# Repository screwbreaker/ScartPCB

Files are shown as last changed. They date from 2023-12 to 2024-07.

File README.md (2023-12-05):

# ScartPCB
A little PCB to buld a SCART cable for console and old computers

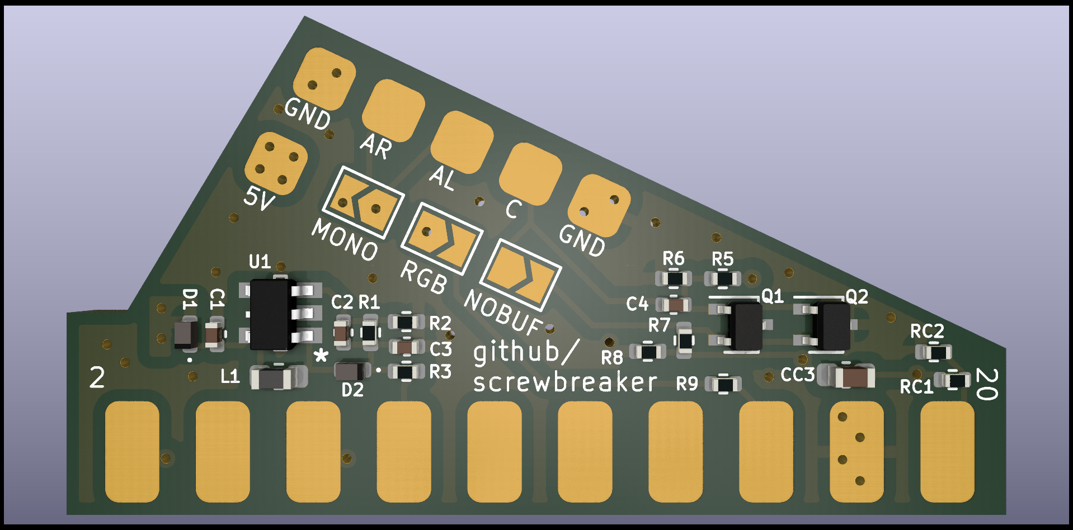
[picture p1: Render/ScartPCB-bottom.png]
Board


### Summary
This is a little PCB made to make easy to assemble a SCART cable for console and old computers.

### History
As anyone else I always made my SCART cables by hand, using THT components. And by soldering them directly on the SCART connector.
And that's pefectly fine. Except for systems like the Mega Drive, that require a lot of componets to be fitted in a small space.
So I thought to build a little PCB that fit inside the SCART connector in oder to make everything more easy and clean.

As example here a comparison between my old handmade cable, and the new one with this PCB:
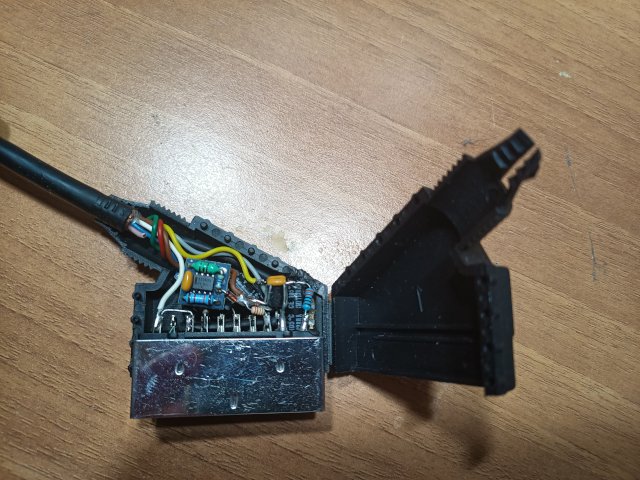
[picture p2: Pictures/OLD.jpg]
OLD

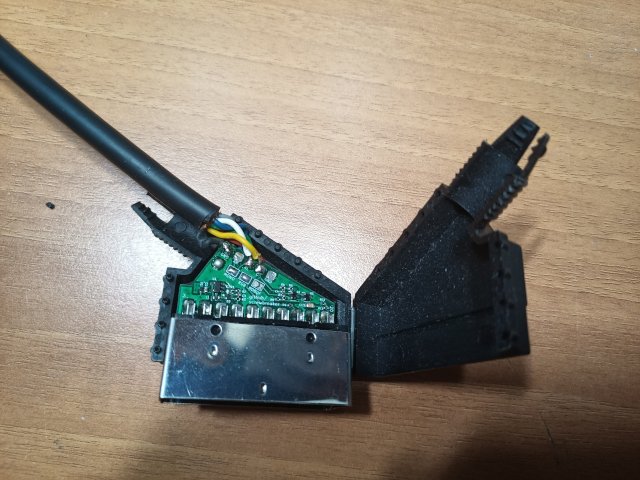
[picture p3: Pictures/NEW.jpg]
NEW


Of course, there are other project like this around. But none of them have all the stuff I wanted.
My requirements was a buffer for the csync and a boost converter for the 12V.

My original plan was to make a PCB for each console.
But, I managed this PCB in a way that can be used almost in any case.
With this PCB is possible to make a SCART cable for almost every console and computer. It is pretty versatile.
And is made to fit inside the cheapest SCART connectors available online.

### Basic informations
The components value in the schematic and in the BOM are for a PAL Mega Drive.
For other systems, refer to the SCART diagram of the secific system.

### How it work
The PCB allow to put components in series and in parallel with the signals.
This allow to use this PCB to buld almost any SCART cable for almost any system.

To make a Mega Drive cable is necessary to put a 220uF capacitor in series with the RGB signals, since is really complicated to find small, and cheap SMD capacitors of this value, the PCB allow to put multiple capacitors in parallel. So, to make a 220uF capacitor is possible to put two 100uF 1206 plus one 22uF 0603.
Probably the 22uF are not really required, but I found the space for some extra footprint in the PCB, so the total value can be easily adjusted.

For example to make a SNES cable put a 0 ohm resistor in place of RR1, RG1, RB1, and place a 75 ohm resitor to ground on each singal by using RR2, RG2, RB2.

If you have a mono audio, like in the first model of Mega Drive, is possible to close the MONO jumper, this short toghether the left and right channel.

The video buffer is there mostly for the Mega Drive, it is nor required on most of the other systems.
To bypass the video buffer, close the NOBUF jumper, in this case do not populate any components on the buffer section.

The RGB jumper can be left open on systems that don't have an RGB output, like a C64.

In general, choose the components to match what do you need to make your video cable. By using 0 ohm resistors as jumper is possible to make almost any combination.

### Csync buffer
The Mega Drive have a problem with the csync signal.
The csync is connected to the input pin of the encoder, not to the output pin.
This can cause some issue on some TV sets. That's why I placed a buffer on the line.

The csync on the Mega Drive is also a TTL level signal, to compensate this a 300-470 ohm reistor can be placed in series with the signal to reduce the voltage to something more like to the standard.
Most of the time also a 220uF capacitor in series with the signal is required.
Not only the Mega Drive use a TTL signal on the csync, it cab be present also on other systems.

Unfortunately not all TV do like this values for the csync line.
So, the values can be adjusted to match your TV set requirements.
Be careful with the level of the signals, they must be in a range that do not cause any damage to your TV.

The values on the csync line, that are on the schematic or in the BOM are for a PAL Mega Drive.
With this set of components I can use my modded MD on my TV, by switching from PAL to NTSC withouth any issue.

Other systems don't have this issue.
The buffer can be bypassed if not needed by closing the NOBUF jumper.
In this case, do not populate any component on the buffer section.

### 12V booster
There is a little boost converter to step up the 5V and get the 12V required for the 4:3 aspect ration.
This is the only way to have the switch voltage.
Some systems, like Amiga or SNES do have the 12V on the connector. But, due to the small space on the PCB, is not possible to use it.

### BOM
The BOM is for a PAL Mega Drive.
To make SCART cables for other system choose the components according to the specific schematic.
Use 0 ohm resistors as jumper where needed.

For the boost converter TPS61040DBVR and TPS61041DBVR are equivalent for this application.

For the buffer any pair of complementary transistors can be used, the package must be SC-70 or equivalent.

### PCB Manufacturing
Unfortunately, due to the space constraints inside the SCART connector, this PCB is a 4 layer board.
And for the same reason, some components are 0402.

The PCB still very cheap to produce, since it is very small, and it use standard vias and traces.

Soldering 0402 components by hand require a bit of skill on soldering.

### Bonus
All the SCART connectors I bought have an hawful issue. The cable gland, the plastic thing that close the SCART shell, is made out the most brittle material in the world.
Initially, I thought that this was because I bought the cheapest SCART connector available on internet.
However even the ones bought on trusth resellers or on electronic shops have this issue.
So, I made a replacement that can be 3D printed. It's far to be perfect, I have no skills on 3D printing. But it do the job.
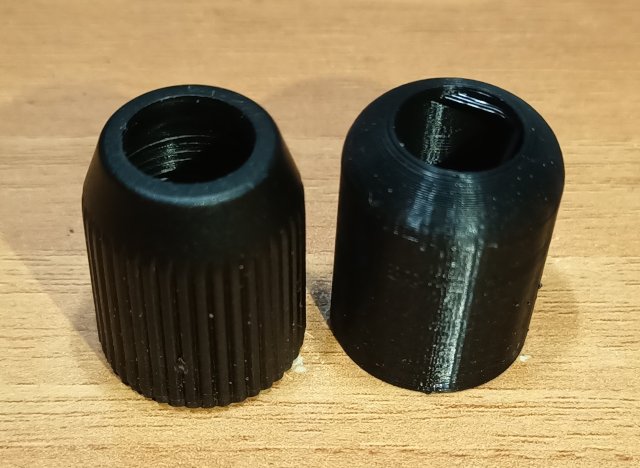
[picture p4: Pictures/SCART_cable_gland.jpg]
SCART_cable_gland


### License
The PCBs are under the CERN OHL license.
The firmwares, under the GPL3.

This is an OPEN project.
So, like any other project like this, the hope is that others can improve it an reshare with the community.
Don't go out this basic guideline.

### Disclaimer
The hardware and the software are provided to you 'as is' and without any express or implied warranties whatsoever with respect to its functionality, operability or use, including, without limitation, any implied warranties of merchantability, fitness for a particular purpose or infringement. We expressly disclaim any liability whatsoever for any direct, indirect, consequential, incidental or special damages, including, without limitation, lost revenues, lost profits, losses resulting from business interruption or loss of data, regardless of the form of action or legal theory under which the liability may be asserted, even if advised of the possibility or likelihood of such damages.

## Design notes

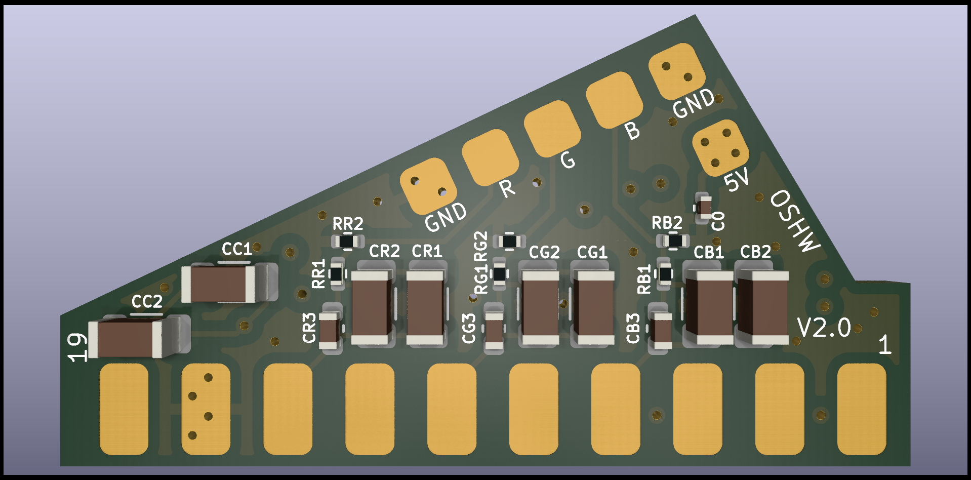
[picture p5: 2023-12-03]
Render/ScartPCB-top.png

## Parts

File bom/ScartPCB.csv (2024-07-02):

Source: | /home/francesco/KiCad_Projects/ScartPCB/ScartPCB.kicad_sch
Date: | mar 2 lug 2024, 21:53:10
Tool: | Eeschema 6.0.11-2627ca5db0~126~ubuntu20.04.1
Generator: | /usr/share/kicad/plugins/bom_csv_grouped_by_value.py
Component Count: | 34
Individual Components:
Item | Qty | Reference(s) | Value | LibPart | Footprint | Datasheet | Datasheet | Description | Footprint | Manufacturer | Manufacturer_Part_Number | Package | Reference | Value
 |  | C0 | 100nF | Device:C | Capacitor_SMD:C_0402_1005Metric | https://www.mouser.it/datasheet/2/447/UPY_NP0X5R_01005_4V_to_25V_V10-3003057.pdf | ~ | 16V 100nF X7R ±10% 0402 Multilayer Ceramic Capacitors MLCC - SMD/SMT ROHS |  | YAEGO | CC0402KRX7R7BB104 | 0402 | C | C
 |  | C1 | 4.7uF | Device:C | Capacitor_SMD:C_0402_1005Metric | https://eu.mouser.com/datasheet/2/40/Kyocera_AVX_Components_CT_Series_e-2933596.pdf | ~ | 0402 Multilayer Ceramic Capacitors MLCC - SMD/SMT ROHS |  | Kyocera AVX | CM05X5R475M25AH | 0402 | C | C
 |  | C2 | 10pF | Device:C | Capacitor_SMD:C_0402_1005Metric | https://www.mouser.it/datasheet/2/210/WTC_MLCC_General_Purpose-1534899.pdf | ~ | 50V 10pF NP0 ±5% 0402 Multilayer Ceramic Capacitors MLCC - SMD/SMT ROHS |  | Walsin | 0402N100J500CT | 0402 | C | C
 |  | C3 | 1uF | Device:C | Capacitor_SMD:C_0402_1005Metric | https://eu.mouser.com/datasheet/2/281/1/GRM155R61E105MA12_01A-1983855.pdf | ~ | 0402 Multilayer Ceramic Capacitors MLCC - SMD/SMT ROHS |  | Murata Electronics | GRM155R61E105MA12D | 0402 | C | C
 |  | C4 | 100nF | Device:C | Capacitor_SMD:C_0402_1005Metric | https://www.mouser.it/datasheet/2/447/UPY_NP0X5R_01005_4V_to_25V_V10-3003057.pdf | ~ | 16V 100nF X7R ±10% 0402 Multilayer Ceramic Capacitors MLCC - SMD/SMT ROHS |  | YAEGO | CC0402KRX7R7BB104 | 0402 | C | C
 |  | CB1 | 100uF | Device:C | Capacitor_SMD:C_1206_3216Metric | https://eu.mouser.com/datasheet/2/281/1/GRM31CR61A107ME05_01A-2066674.pdf | ~ | 10V 100uF X5R ±20% 1206 Multilayer Ceramic Capacitors MLCC - SMD/SMT ROHS |  | Murata Electronics | GRM31CR61A107ME05L | 1206 | C | C
 |  | CB2 | 100uF | Device:C | Capacitor_SMD:C_1206_3216Metric | https://eu.mouser.com/datasheet/2/281/1/GRM31CR61A107ME05_01A-2066674.pdf | ~ | 10V 100uF X5R ±20% 1206 Multilayer Ceramic Capacitors MLCC - SMD/SMT ROHS |  | Murata Electronics | GRM31CR61A107ME05L | 1206 | C | C
 |  | CB3 | 22uF | Device:C | Capacitor_SMD:C_0603_1608Metric | https://eu.mouser.com/datasheet/2/585/MLCC-1837944.pdf | ~ | 10V 22uF X5R ±20% 0603 Multilayer Ceramic Capacitors MLCC - SMD/SMT ROHS |  | Samsung | CL10A226MP8NUNE | 0603 | C | C
 |  | CC1 | 100uF | Device:C | Capacitor_SMD:C_1206_3216Metric | https://eu.mouser.com/datasheet/2/281/1/GRM31CR61A107ME05_01A-2066674.pdf | ~ | 10V 100uF X5R ±20% 1206 Multilayer Ceramic Capacitors MLCC - SMD/SMT ROHS |  | Murata Electronics | GRM31CR61A107ME05L | 1206 | C | C
 |  | CC2 | 100uF | Device:C | Capacitor_SMD:C_1206_3216Metric | https://eu.mouser.com/datasheet/2/281/1/GRM31CR61A107ME05_01A-2066674.pdf | ~ | 10V 100uF X5R ±20% 1206 Multilayer Ceramic Capacitors MLCC - SMD/SMT ROHS |  | Murata Electronics | GRM31CR61A107ME05L | 1206 | C | C
 |  | CC3 | 22uF | Device:C | Capacitor_SMD:C_0603_1608Metric | https://eu.mouser.com/datasheet/2/585/MLCC-1837944.pdf | ~ | 10V 22uF X5R ±20% 0603 Multilayer Ceramic Capacitors MLCC - SMD/SMT ROHS |  | Samsung | CL10A226MP8NUNE | 0603 | C | C
 |  | CG1 | 100uF | Device:C | Capacitor_SMD:C_1206_3216Metric | https://eu.mouser.com/datasheet/2/281/1/GRM31CR61A107ME05_01A-2066674.pdf | ~ | 10V 100uF X5R ±20% 1206 Multilayer Ceramic Capacitors MLCC - SMD/SMT ROHS |  | Murata Electronics | GRM31CR61A107ME05L | 1206 | C | C
 |  | CG2 | 100uF | Device:C | Capacitor_SMD:C_1206_3216Metric | https://eu.mouser.com/datasheet/2/281/1/GRM31CR61A107ME05_01A-2066674.pdf | ~ | 10V 100uF X5R ±20% 1206 Multilayer Ceramic Capacitors MLCC - SMD/SMT ROHS |  | Murata Electronics | GRM31CR61A107ME05L | 1206 | C | C
 |  | CG3 | 22uF | Device:C | Capacitor_SMD:C_0603_1608Metric | https://eu.mouser.com/datasheet/2/585/MLCC-1837944.pdf | ~ | 10V 22uF X5R ±20% 0603 Multilayer Ceramic Capacitors MLCC - SMD/SMT ROHS |  | Samsung | CL10A226MP8NUNE | 0603 | C | C
 |  | CR1 | 100uF | Device:C | Capacitor_SMD:C_1206_3216Metric | https://eu.mouser.com/datasheet/2/281/1/GRM31CR61A107ME05_01A-2066674.pdf | ~ | 10V 100uF X5R ±20% 1206 Multilayer Ceramic Capacitors MLCC - SMD/SMT ROHS |  | Murata Electronics | GRM31CR61A107ME05L | 1206 | C | C
 |  | CR2 | 100uF | Device:C | Capacitor_SMD:C_1206_3216Metric | https://eu.mouser.com/datasheet/2/281/1/GRM31CR61A107ME05_01A-2066674.pdf | ~ | 10V 100uF X5R ±20% 1206 Multilayer Ceramic Capacitors MLCC - SMD/SMT ROHS |  | Murata Electronics | GRM31CR61A107ME05L | 1206 | C | C
 |  | CR3 | 22uF | Device:C | Capacitor_SMD:C_0603_1608Metric | https://eu.mouser.com/datasheet/2/585/MLCC-1837944.pdf | ~ | 10V 22uF X5R ±20% 0603 Multilayer Ceramic Capacitors MLCC - SMD/SMT ROHS |  | Samsung | CL10A226MP8NUNE | 0603 | C | C
 |  | D1 | D_Schottky | Device:D_Schottky | Diode_SMD:D_0402_1005Metric | https://eu.mouser.com/datasheet/2/80/CDBQR0130R_HF_RevC796140-2489182.pdf | ~ |  |  | Comchip Technology | CDBQR0130R-HF | 0402 | D | D_Schottky
 |  | D2 | D_Schottky | Device:D_Schottky | Diode_SMD:D_0402_1005Metric | https://eu.mouser.com/datasheet/2/80/CDBQR0130R_HF_RevC796140-2489182.pdf | ~ |  |  | Comchip Technology | CDBQR0130R-HF | 0402 | D | D_Schottky
 |  | L1 | 10uH | Device:L | Inductor_SMD:L_0603_1608Metric | https://product.tdk.com/system/files/dam/doc/product/inductor/inductor/smd/catalog/inductor_commercial_decoupling_mlz1608_en.pdf | ~ | 250mA 10uH ±20% 90mA 1.05Ω 0603 Inductors (SMD) ROHS |  | TDK | MLZ1608M100WT000 | 0603 | L | L
 |  | Q1 | BC847W | Transistor_BJT:BC847W | Package_TO_SOT_SMD:SOT-323_SC-70 | https://eu.mouser.com/datasheet/2/916/BC847XW_SER-3081653.pdf | http://www.infineon.com/dgdl/Infineon-BC847SERIES_BC848SERIES_BC849SERIES_BC850SERIES-DS-v01_01-en.pdf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 | Bipolar Transistors - BJT BC847W/SOT323/SC-70 | Package_TO_SOT_SMD:SOT-323_SC-70 | Nexperia | BC847W,115 | SC-70 | Q | BC847W
 |  | Q2 | BC857W | Transistor_BJT:BC857W | Package_TO_SOT_SMD:SOT-323_SC-70 | https://eu.mouser.com/datasheet/2/916/BC856W_BC857W_BC858W-1319299.pdf | http://www.infineon.com/dgdl/Infineon-BC857SERIES_BC858SERIES_BC859SERIES_BC860SERIES-DS-v01_01-en.pdf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 | Bipolar Transistors - BJT BC857W/SOT323/SC-70 | Package_TO_SOT_SMD:SOT-323_SC-70 | Nexperia | BC857W,135 | SC-70 | Q | BC857W
 |  | R1 | 1.6M | Device:R | Resistor_SMD:R_0402_1005Metric | https://www.mouser.it/datasheet/2/447/PYu_RC_Group_51_RoHS_L_11-1984063.pdf | ~ | 62.5mW Thick Film Resistors 50V ±100ppm/℃ ±1% -55℃~+155℃ 1.6MΩ 0402 Chip Resistor - Surface Mount ROHS |  | YAEGO | RC0402FR-071M6L | 0402 | R | R
 |  | R2 | 200K | Device:R | Resistor_SMD:R_0402_1005Metric | https://www.mouser.it/datasheet/2/447/PYu_RC_Group_51_RoHS_L_11-1984063.pdf | ~ | 62.5mW Thick Film Resistors 50V ±100ppm/℃ ±1% -55℃~+155℃ 200kΩ 0402 Chip Resistor - Surface Mount ROHS |  | Royalohm | 0402WGF2003TCE | 0402 | R | R
 |  | R3 | 1K | Device:R | Resistor_SMD:R_0402_1005Metric | https://www.mouser.it/datasheet/2/1365/GeneralPurpose-2498088.pdf | https://www.mouser.it/datasheet/2/1365/GeneralPurpose-2498088.pdf | 62.5mW Thick Film Resistors 50V ±100ppm/℃ ±1% -55℃~+155℃ 1kΩ 0402 Chip Resistor - Surface Mount ROHS | Resistor_SMD:R_0402_1005Metric | Royalohm | 0402WGF1001TCE | 0402 | R3 | 1K
 |  | R5 | 1M | Device:R | Resistor_SMD:R_0402_1005Metric | https://eu.mouser.com/datasheet/2/1365/1-3044649.pdf | ~ | Thick Film Resistors - SMD 0402 1/16W 1% 1M T/R-10000 |  | Royalohm | 0402WGF1004TCE | 0402 | R | R
 |  | R6 | 1M | Device:R | Resistor_SMD:R_0402_1005Metric | https://eu.mouser.com/datasheet/2/1365/1-3044649.pdf | ~ | Thick Film Resistors - SMD 0402 1/16W 1% 1M T/R-10000 |  | Royalohm | 0402WGF1004TCE | 0402 | R | R
 |  | R7 | 0 | Device:R | Resistor_SMD:R_0402_1005Metric | https://eu.mouser.com/datasheet/2/1365/1-3044649.pdf | ~ | Thick Film Resistors - SMD 0402 1/16W 1% 0R T/R-10000 |  | Royalohm | 0402WGF750JTCE | 0402 | R | R
 |  | R9 | 180 | Device:R | Resistor_SMD:R_0402_1005Metric | https://www.mouser.it/datasheet/2/1365/HighPowerHP-2498106.pdf | ~ | 100mW 50V ±100ppm/℃ ±1% -55℃~+155℃ 180Ω 0402 Chip Resistor - Surface Mount ROHS |  | Royalohm | HP02WAF1800TCE | 0402 | R | R
 |  | RB1 | 75 | Device:R | Resistor_SMD:R_0402_1005Metric | https://eu.mouser.com/datasheet/2/1365/GeneralPurpose-2498088.pdf | ~ | 62.5mW 50V ±100ppm/℃ ±1% -55℃~+155℃ 75Ω 0402 Chip Resistor - Surface Mount ROHS |  | Royalohm | 0402WGF750JTCE | 0402 | R | R
 |  | RC1 | 300 | Device:R | Resistor_SMD:R_0402_1005Metric | https://www.mouser.it/datasheet/2/447/PYu_RC_Group_51_RoHS_L_11-1984063.pdf | ~ | 62.5mW Thick Film Resistors 50V ±100ppm/℃ ±5% -55℃~+155℃ 300Ω 0402 Chip Resistor - Surface Mount ROHS |  | Yaego | RC0402JR-07300RL | 0402 | R | R
 |  | RG1 | 75 | Device:R | Resistor_SMD:R_0402_1005Metric | https://eu.mouser.com/datasheet/2/1365/GeneralPurpose-2498088.pdf | ~ | 62.5mW 50V ±100ppm/℃ ±1% -55℃~+155℃ 75Ω 0402 Chip Resistor - Surface Mount ROHS |  | Royalohm | 0402WGF750JTCE | 0402 | R | R
 |  | RR1 | 75 | Device:R | Resistor_SMD:R_0402_1005Metric | https://eu.mouser.com/datasheet/2/1365/GeneralPurpose-2498088.pdf | ~ | 62.5mW 50V ±100ppm/℃ ±1% -55℃~+155℃ 75Ω 0402 Chip Resistor - Surface Mount ROHS |  | Royalohm | 0402WGF750JTCE | 0402 | R | R
 |  | U1 | TPS61040DBVR | TPS61040DBVR:TPS61040DBVR | Footprints:TPS61040DBVR | https://www.ti.com/lit/ds/symlink/tps61040.pdf |  | 28-V, 400-mA Switch Boost Converter in SOT-23 for LCD and White LED Applications | DBV0005A | Texas Instruments | TPS61040DBVR | SOT-23-5 | U* | TPS61040DBVR
Collated Components:
Item | Qty | Reference(s) | Value | LibPart | Footprint | Datasheet | Datasheet | Description | Footprint | Manufacturer | Manufacturer_Part_Number | Package | Reference | Value
1 | 2 | C0, C4 | 100nF | Device:C | Capacitor_SMD:C_0402_1005Metric | https://www.mouser.it/datasheet/2/447/UPY_NP0X5R_01005_4V_to_25V_V10-3003057.pdf | ~ | 16V 100nF X7R ±10% 0402 Multilayer Ceramic Capacitors MLCC - SMD/SMT ROHS |  | YAEGO | CC0402KRX7R7BB104 | 0402 | C | C
2 | 1 | C1 | 4.7uF | Device:C | Capacitor_SMD:C_0402_1005Metric | https://eu.mouser.com/datasheet/2/40/Kyocera_AVX_Components_CT_Series_e-2933596.pdf | ~ | 0402 Multilayer Ceramic Capacitors MLCC - SMD/SMT ROHS |  | Kyocera AVX | CM05X5R475M25AH | 0402 | C | C
3 | 1 | C2 | 10pF | Device:C | Capacitor_SMD:C_0402_1005Metric | https://www.mouser.it/datasheet/2/210/WTC_MLCC_General_Purpose-1534899.pdf | ~ | 50V 10pF NP0 ±5% 0402 Multilayer Ceramic Capacitors MLCC - SMD/SMT ROHS |  | Walsin | 0402N100J500CT | 0402 | C | C
4 | 1 | C3 | 1uF | Device:C | Capacitor_SMD:C_0402_1005Metric | https://eu.mouser.com/datasheet/2/281/1/GRM155R61E105MA12_01A-1983855.pdf | ~ | 0402 Multilayer Ceramic Capacitors MLCC - SMD/SMT ROHS |  | Murata Electronics | GRM155R61E105MA12D | 0402 | C | C
5 | 8 | CB1, CB2, CC1, CC2, CG1, CG2, CR1, CR2 | 100uF | Device:C | Capacitor_SMD:C_1206_3216Metric | https://eu.mouser.com/datasheet/2/281/1/GRM31CR61A107ME05_01A-2066674.pdf | ~ | 10V 100uF X5R ±20% 1206 Multilayer Ceramic Capacitors MLCC - SMD/SMT ROHS |  | Murata Electronics | GRM31CR61A107ME05L | 1206 | C | C
6 | 4 | CB3, CC3, CG3, CR3 | 22uF | Device:C | Capacitor_SMD:C_0603_1608Metric | https://eu.mouser.com/datasheet/2/585/MLCC-1837944.pdf | ~ | 10V 22uF X5R ±20% 0603 Multilayer Ceramic Capacitors MLCC - SMD/SMT ROHS |  | Samsung | CL10A226MP8NUNE | 0603 | C | C
7 | 2 | D1, D2 | D_Schottky | Device:D_Schottky | Diode_SMD:D_0402_1005Metric | https://eu.mouser.com/datasheet/2/80/CDBQR0130R_HF_RevC796140-2489182.pdf | ~ |  |  | Comchip Technology | CDBQR0130R-HF | 0402 | D | D_Schottky
8 | 1 | L1 | 10uH | Device:L | Inductor_SMD:L_0603_1608Metric | https://product.tdk.com/system/files/dam/doc/product/inductor/inductor/smd/catalog/inductor_commercial_decoupling_mlz1608_en.pdf | ~ | 250mA 10uH ±20% 90mA 1.05Ω 0603 Inductors (SMD) ROHS |  | TDK | MLZ1608M100WT000 | 0603 | L | L
9 | 1 | Q1 | BC847W | Transistor_BJT:BC847W | Package_TO_SOT_SMD:SOT-323_SC-70 | https://eu.mouser.com/datasheet/2/916/BC847XW_SER-3081653.pdf | http://www.infineon.com/dgdl/Infineon-BC847SERIES_BC848SERIES_BC849SERIES_BC850SERIES-DS-v01_01-en.pdf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 | Bipolar Transistors - BJT BC847W/SOT323/SC-70 | Package_TO_SOT_SMD:SOT-323_SC-70 | Nexperia | BC847W,115 | SC-70 | Q | BC847W
10 | 1 | Q2 | BC857W | Transistor_BJT:BC857W | Package_TO_SOT_SMD:SOT-323_SC-70 | https://eu.mouser.com/datasheet/2/916/BC856W_BC857W_BC858W-1319299.pdf | http://www.infineon.com/dgdl/Infineon-BC857SERIES_BC858SERIES_BC859SERIES_BC860SERIES-DS-v01_01-en.pdf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 | Bipolar Transistors - BJT BC857W/SOT323/SC-70 | Package_TO_SOT_SMD:SOT-323_SC-70 | Nexperia | BC857W,135 | SC-70 | Q | BC857W
11 | 1 | R1 | 1.6M | Device:R | Resistor_SMD:R_0402_1005Metric | https://www.mouser.it/datasheet/2/447/PYu_RC_Group_51_RoHS_L_11-1984063.pdf | ~ | 62.5mW Thick Film Resistors 50V ±100ppm/℃ ±1% -55℃~+155℃ 1.6MΩ 0402 Chip Resistor - Surface Mount ROHS |  | YAEGO | RC0402FR-071M6L | 0402 | R | R
12 | 1 | R2 | 200K | Device:R | Resistor_SMD:R_0402_1005Metric | https://www.mouser.it/datasheet/2/447/PYu_RC_Group_51_RoHS_L_11-1984063.pdf | ~ | 62.5mW Thick Film Resistors 50V ±100ppm/℃ ±1% -55℃~+155℃ 200kΩ 0402 Chip Resistor - Surface Mount ROHS |  | Royalohm | 0402WGF2003TCE | 0402 | R | R
13 | 1 | R3 | 1K | Device:R | Resistor_SMD:R_0402_1005Metric | https://www.mouser.it/datasheet/2/1365/GeneralPurpose-2498088.pdf | https://www.mouser.it/datasheet/2/1365/GeneralPurpose-2498088.pdf | 62.5mW Thick Film Resistors 50V ±100ppm/℃ ±1% -55℃~+155℃ 1kΩ 0402 Chip Resistor - Surface Mount ROHS | Resistor_SMD:R_0402_1005Metric | Royalohm | 0402WGF1001TCE | 0402 | R3 | 1K
14 | 2 | R5, R6 | 1M | Device:R | Resistor_SMD:R_0402_1005Metric | https://eu.mouser.com/datasheet/2/1365/1-3044649.pdf | ~ | Thick Film Resistors - SMD 0402 1/16W 1% 1M T/R-10000 |  | Royalohm | 0402WGF1004TCE | 0402 | R | R
15 | 1 | R7 | 0 | Device:R | Resistor_SMD:R_0402_1005Metric | https://eu.mouser.com/datasheet/2/1365/1-3044649.pdf | ~ | Thick Film Resistors - SMD 0402 1/16W 1% 0R T/R-10000 |  | Royalohm | 0402WGF750JTCE | 0402 | R | R
16 | 1 | R9 | 180 | Device:R | Resistor_SMD:R_0402_1005Metric | https://www.mouser.it/datasheet/2/1365/HighPowerHP-2498106.pdf | ~ | 100mW 50V ±100ppm/℃ ±1% -55℃~+155℃ 180Ω 0402 Chip Resistor - Surface Mount ROHS |  | Royalohm | HP02WAF1800TCE | 0402 | R | R
17 | 3 | RB1, RG1, RR1 | 75 | Device:R | Resistor_SMD:R_0402_1005Metric | https://eu.mouser.com/datasheet/2/1365/GeneralPurpose-2498088.pdf | ~ | 62.5mW 50V ±100ppm/℃ ±1% -55℃~+155℃ 75Ω 0402 Chip Resistor - Surface Mount ROHS |  | Royalohm | 0402WGF750JTCE | 0402 | R | R
18 | 1 | RC1 | 300 | Device:R | Resistor_SMD:R_0402_1005Metric | https://www.mouser.it/datasheet/2/447/PYu_RC_Group_51_RoHS_L_11-1984063.pdf | ~ | 62.5mW Thick Film Resistors 50V ±100ppm/℃ ±5% -55℃~+155℃ 300Ω 0402 Chip Resistor - Surface Mount ROHS |  | Yaego | RC0402JR-07300RL | 0402 | R | R
19 | 1 | U1 | TPS61040DBVR | TPS61040DBVR:TPS61040DBVR | Footprints:TPS61040DBVR | https://www.ti.com/lit/ds/symlink/tps61040.pdf |  | 28-V, 400-mA Switch Boost Converter in SOT-23 for LCD and White LED Applications | DBV0005A | Texas Instruments | TPS61040DBVR | SOT-23-5 | U* | TPS61040DBVR

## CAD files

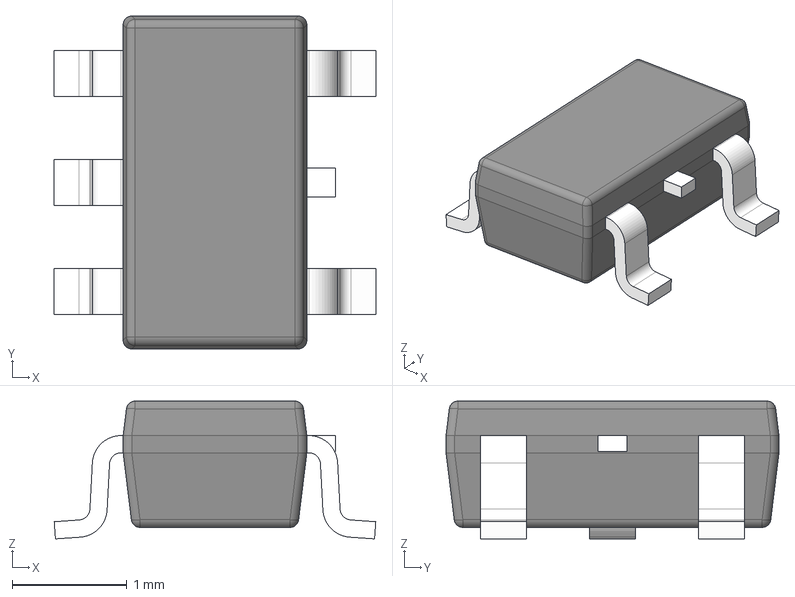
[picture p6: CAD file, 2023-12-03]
3D models/SN74AHC1G125DBVR.stp
2.80 x 2.90 x 1.20 mm
BODY-SOT
LEAD-SOT x 5
LEAD-DUMMY

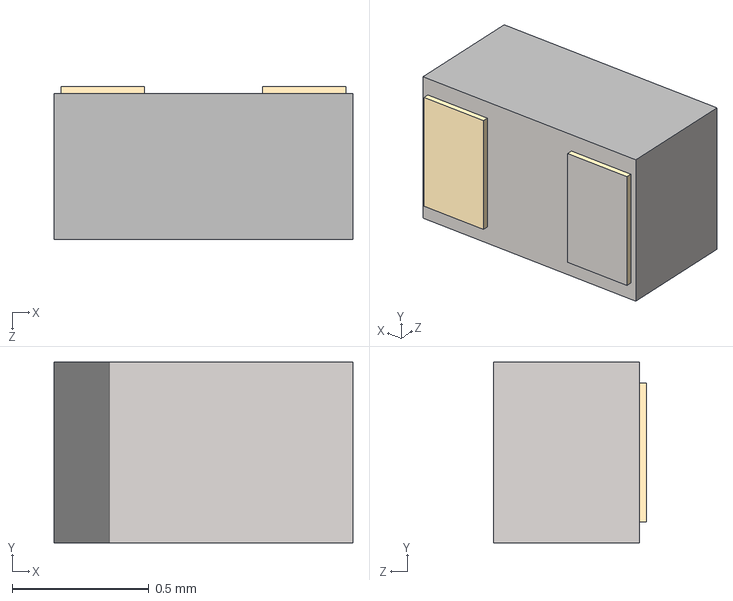
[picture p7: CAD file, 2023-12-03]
3D models/D_0402.step
1.09 x 0.66 x 0.559 mm

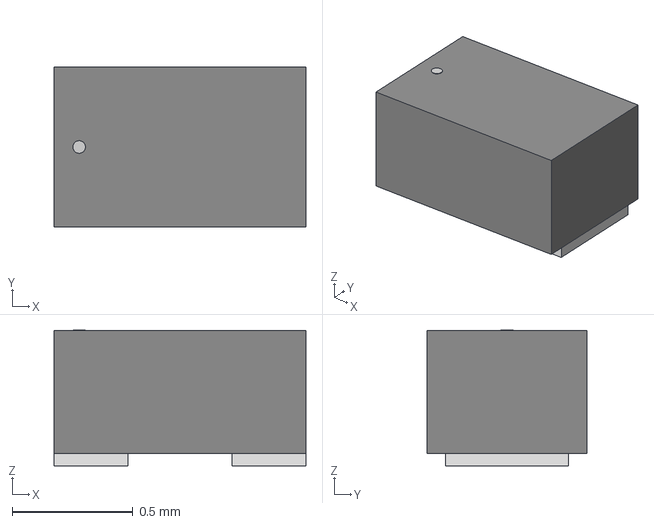
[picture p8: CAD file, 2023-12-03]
3D models/CDBQR0130R.step
1.04 x 0.66 x 0.561 mm

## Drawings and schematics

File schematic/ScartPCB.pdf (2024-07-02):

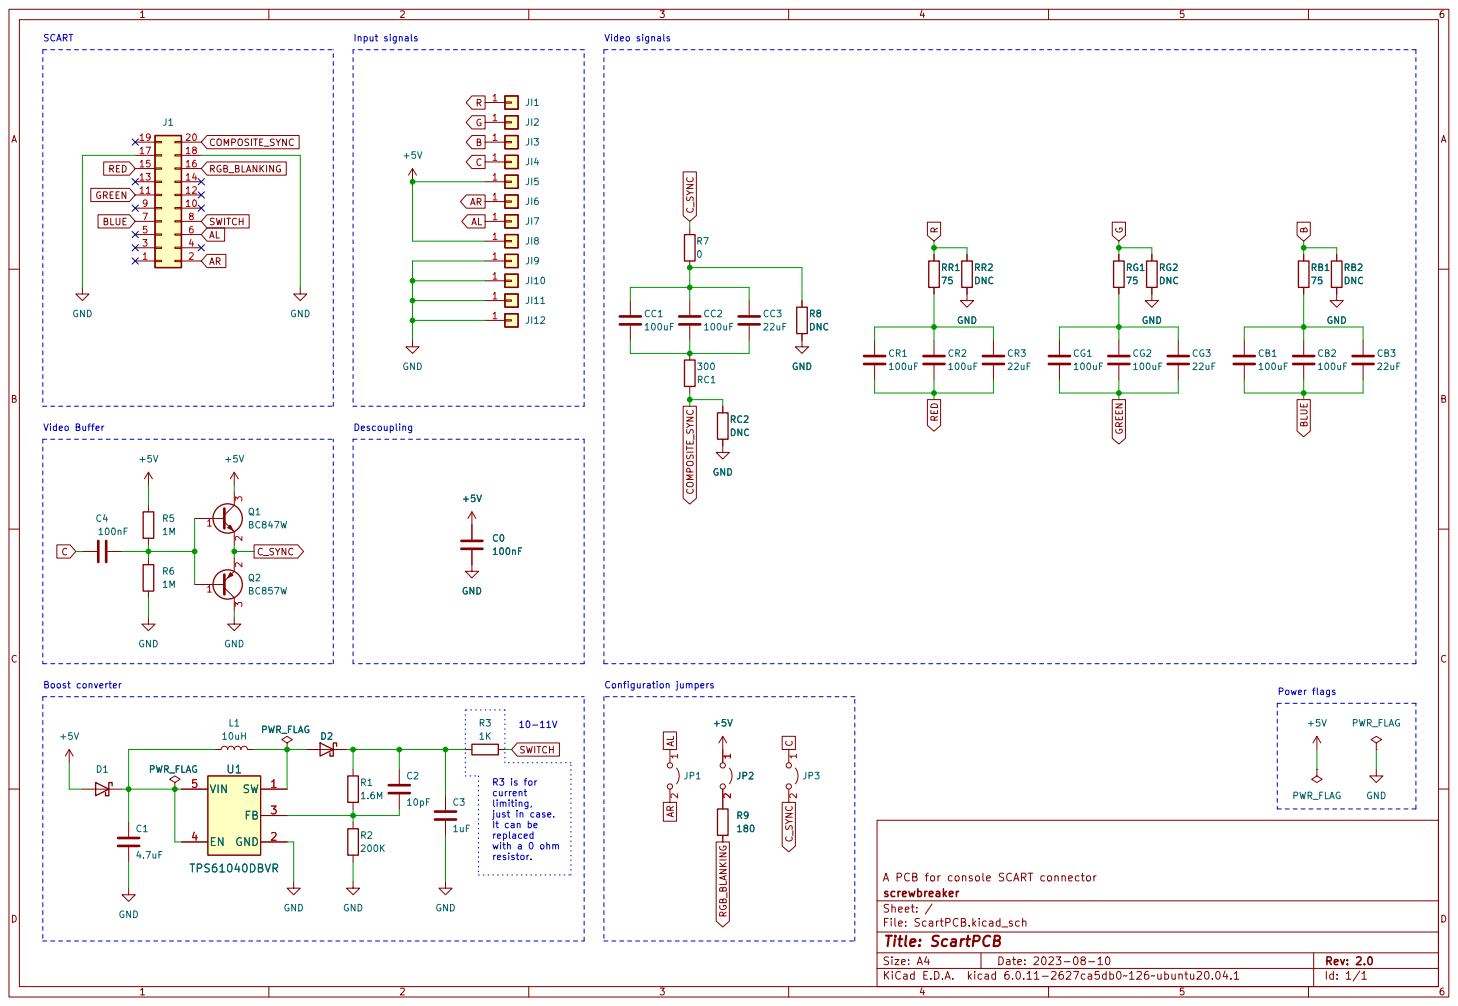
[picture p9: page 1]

File: ScartPCB.kicad_sch Sheet: / screwbreaker A PCB for console SCART connector

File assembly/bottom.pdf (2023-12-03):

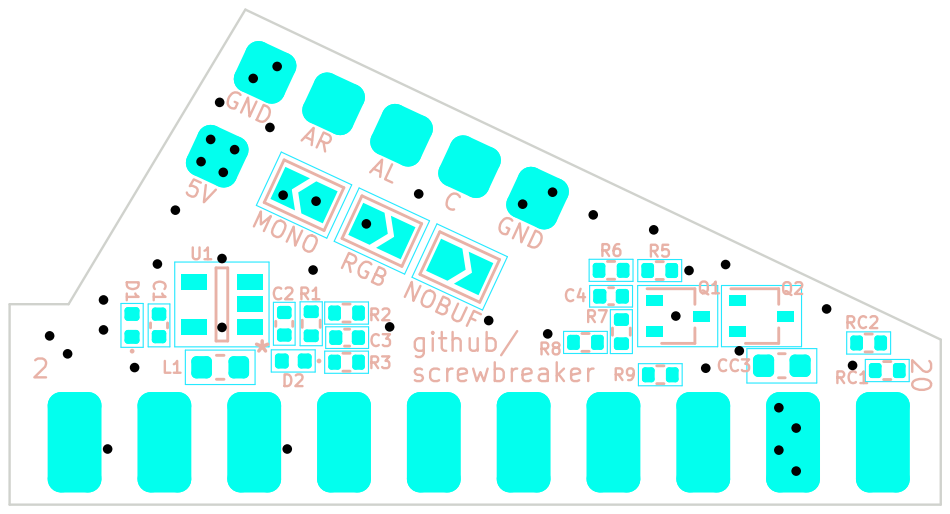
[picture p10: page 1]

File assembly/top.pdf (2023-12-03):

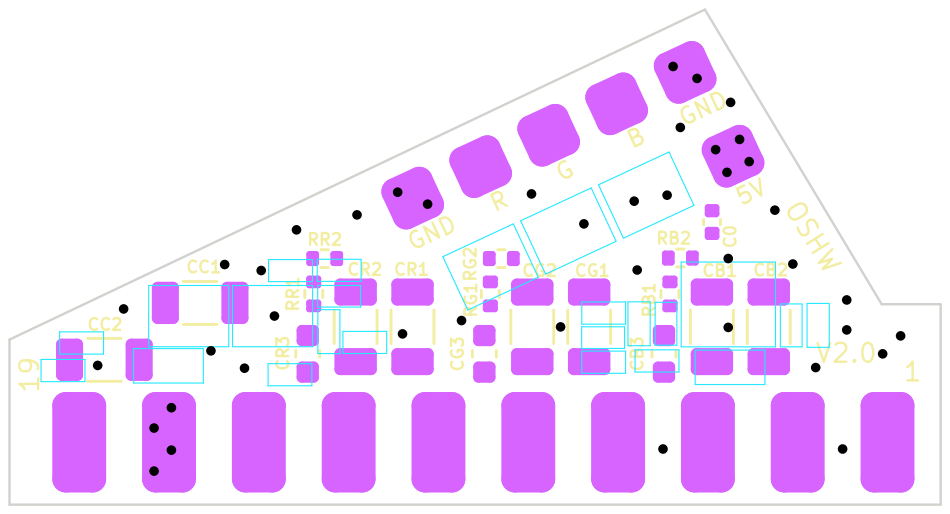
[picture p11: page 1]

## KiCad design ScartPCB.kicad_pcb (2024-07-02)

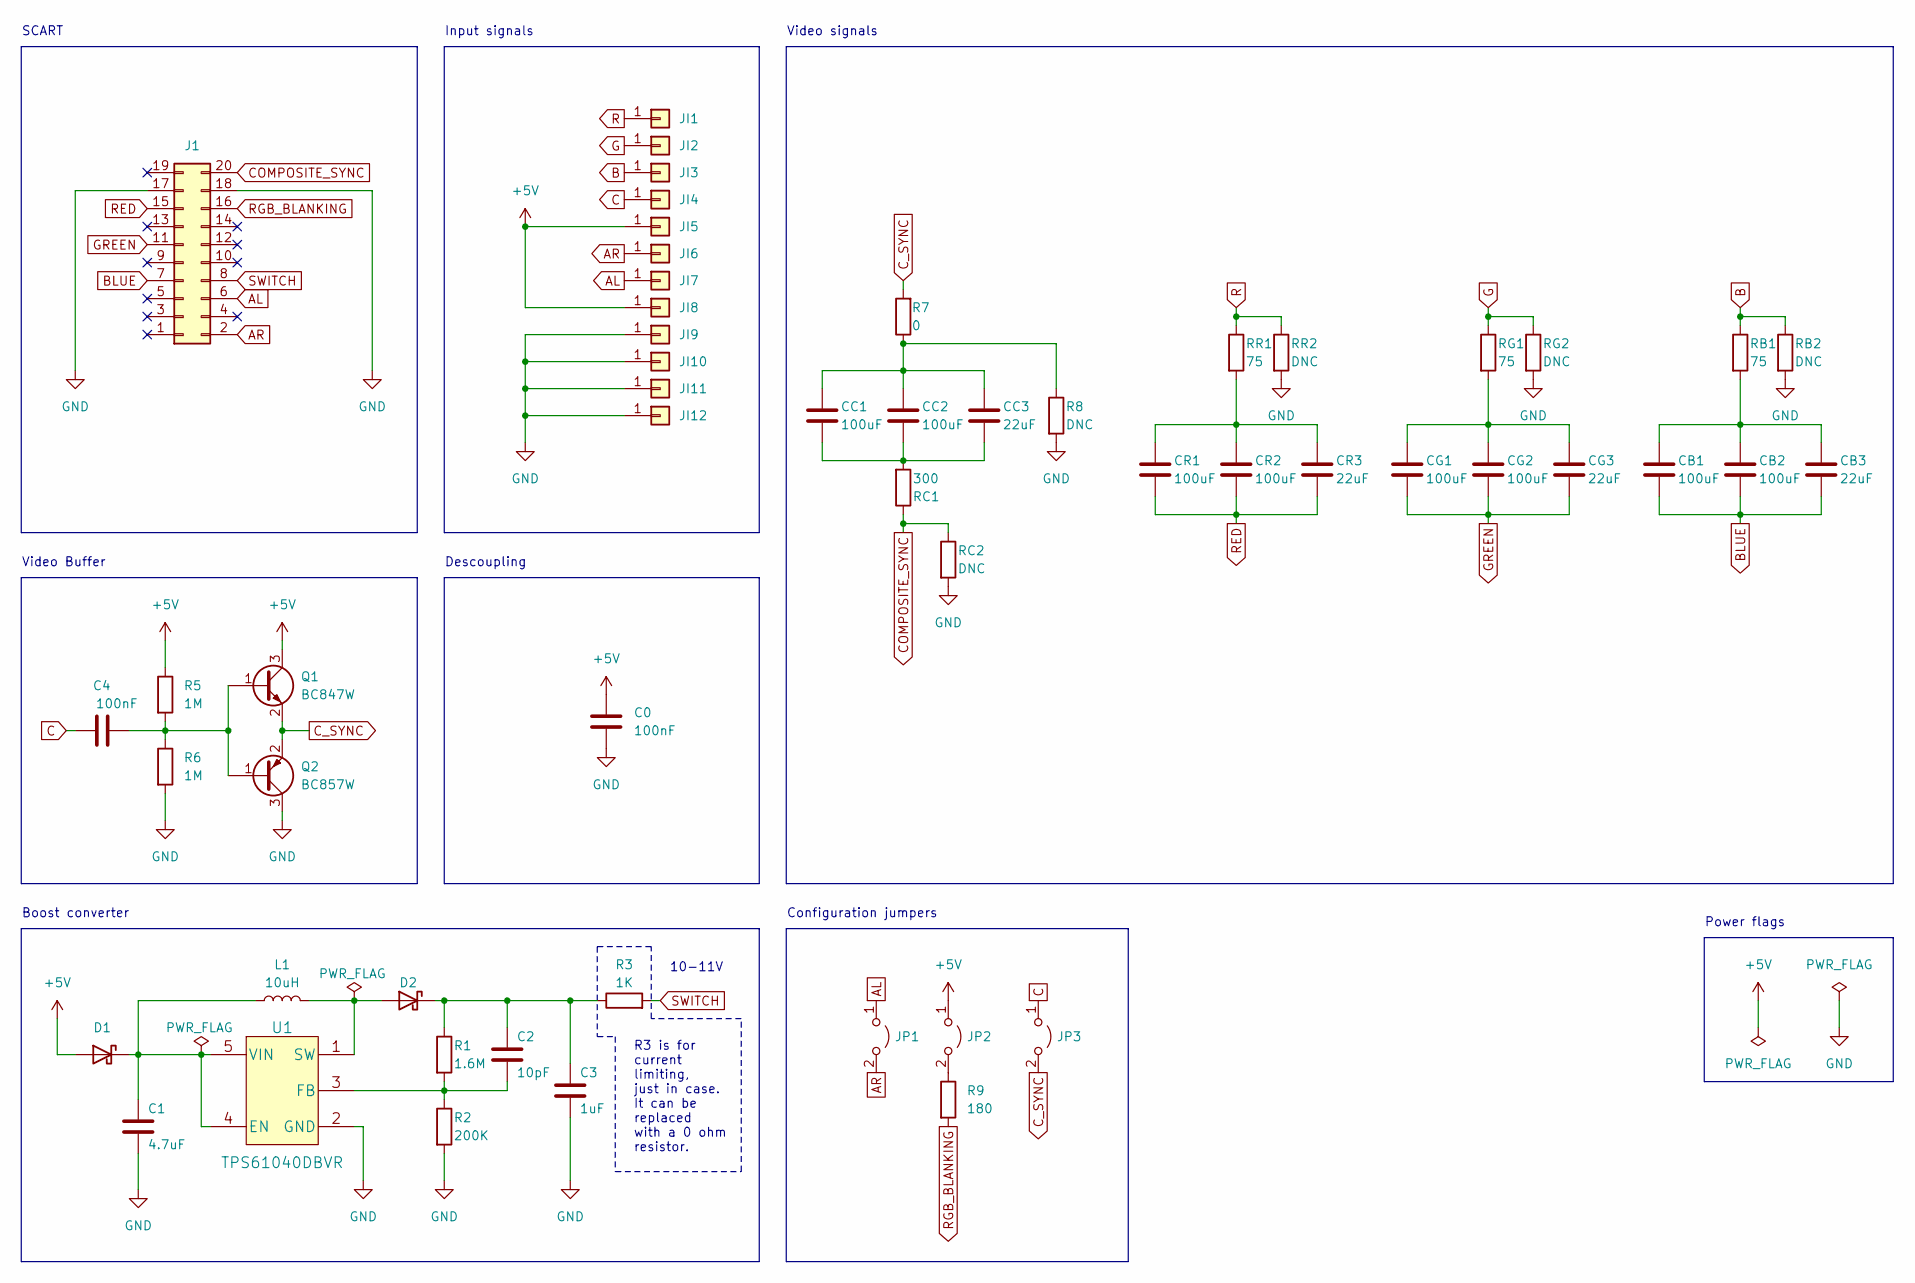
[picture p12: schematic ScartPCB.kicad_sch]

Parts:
C0, C4: 100nF; C_0402_1005Metric; Manufacturer_Part_Number CC0402KRX7R7BB104
C1: 4.7uF; C_0402_1005Metric; Manufacturer_Part_Number CM05X5R475M25AH
C2: 10pF; C_0402_1005Metric; Manufacturer_Part_Number 0402N100J500CT
C3: 1uF; C_0402_1005Metric; Manufacturer_Part_Number GRM155R61E105MA12D
CB1, CB2: 100uF; C_1206_3216Metric; Manufacturer_Part_Number GRM31CR61A107ME05L
CB3: 22uF; C_0603_1608Metric; Manufacturer_Part_Number CL10A226MP8NUNE
CC1, CC2: 100uF; C_1206_3216Metric; Manufacturer_Part_Number GRM31CR61A107ME05L
CC3: 22uF; C_0603_1608Metric; Manufacturer_Part_Number CL10A226MP8NUNE
CG1, CG2: 100uF; C_1206_3216Metric; Manufacturer_Part_Number GRM31CR61A107ME05L
CG3: 22uF; C_0603_1608Metric; Manufacturer_Part_Number CL10A226MP8NUNE
CR1, CR2: 100uF; C_1206_3216Metric; Manufacturer_Part_Number GRM31CR61A107ME05L
CR3: 22uF; C_0603_1608Metric; Manufacturer_Part_Number CL10A226MP8NUNE
D1, D2: D_Schottky; D_0402_1005Metric; Manufacturer_Part_Number CDBQR0130R-HF
J1: Conn_02x10_Odd_Even; SCART
JI1, JI2, JI3, JI4, JI5, JI6, JI7, JI8, JI9, JI10, JI11, JI12: Conn_01x01; PAD2x2
JP1, JP2, JP3: Jumper_2_Open; SolderJumper-2_P1.3mm_Open_TrianglePad1.0x1.5mm
L1: 10uH; L_0603_1608Metric; Manufacturer_Part_Number MLZ1608M100WT000
Q1: BC847W; SOT-323_SC-70; Manufacturer_Part_Number BC847W,115
Q2: BC857W; SOT-323_SC-70; Manufacturer_Part_Number BC857W,135
R1: 1.6M; R_0402_1005Metric; Manufacturer_Part_Number RC0402FR-071M6L
R2: 200K; R_0402_1005Metric; Manufacturer_Part_Number 0402WGF2003TCE
R3: 1K; R_0402_1005Metric; Manufacturer_Part_Number 0402WGF1001TCE
R5, R6: 1M; R_0402_1005Metric; Manufacturer_Part_Number 0402WGF1004TCE
R7: 0; R_0402_1005Metric; Manufacturer_Part_Number 0402WGF750JTCE
R8: DNC; R_0402_1005Metric
R9: 180; R_0402_1005Metric; Manufacturer_Part_Number HP02WAF1800TCE
RB1: 75; R_0402_1005Metric; Manufacturer_Part_Number 0402WGF750JTCE
RB2: DNC; R_0402_1005Metric; Manufacturer_Part_Number 0402WGF750JTCE
RC1: 300; R_0402_1005Metric; Manufacturer_Part_Number RC0402JR-07300RL
RC2: DNC; R_0402_1005Metric
RG1: 75; R_0402_1005Metric; Manufacturer_Part_Number 0402WGF750JTCE
RG2: DNC; R_0402_1005Metric; Manufacturer_Part_Number 0402WGF750JTCE
RR1: 75; R_0402_1005Metric; Manufacturer_Part_Number 0402WGF750JTCE
RR2: DNC; R_0402_1005Metric; Manufacturer_Part_Number 0402WGF750JTCE
U1: TPS61040DBVR; Manufacturer_Part_Number TPS61040DBVR

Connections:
+5V: C0.1, D1.2 (A), JI5.1, JI8.1, JP2.1 (A), Q1.3 (C), R5.1
AL: J1.6, JI7.1, JP1.1 (A)
AR: J1.2, JI6.1, JP1.2 (B)
B: JI3.1, RB1.1, RB2.1
BLUE: CB1.2, CB2.2, CB3.2, J1.7
C: C4.1, JI4.1, JP3.1 (A)
COMPOSITE_SYNC: J1.20, RC1.1, RC2.1
C_SYNC: JP3.2 (B), Q1.2 (E), Q2.2 (E), R7.2
G: JI2.1, RG1.1, RG2.1
GND: C0.2, C1.2, C3.2, J1.17, J1.18, JI9.1, JI10.1, JI11.1, JI12.1, Q2.3 (C), R2.2, R6.2, R8.2, RB2.2, RC2.2, RG2.2, RR2.2, U1.2 (GND)
GREEN: CG1.2, CG2.2, CG3.2, J1.11
unnamed: C1.1, D1.1 (K), L1.1, U1.4 (EN), U1.5 (VIN)
unnamed: C2.1, C3.1, D2.1 (K), R1.1, R3.1
unnamed: C2.2, R1.2, R2.1, U1.3 (FB)
unnamed: C4.2, Q1.1 (B), Q2.1 (B), R5.2, R6.1
unnamed: CB1.1, CB2.1, CB3.1, RB1.2
unnamed: CC1.1, CC2.1, CC3.1, RC1.2
unnamed: CC1.2, CC2.2, CC3.2, R7.1, R8.1
unnamed: CG1.1, CG2.1, CG3.1, RG1.2
unnamed: CR1.1, CR2.1, CR3.1, RR1.2
unnamed: D2.2 (A), L1.2, U1.1 (SW)
unnamed: JP2.2 (B), R9.1
R: JI1.1, RR1.1, RR2.1
RED: CR1.2, CR2.2, CR3.2, J1.15
RGB_BLANKING: J1.16, R9.2
SWITCH: J1.8, R3.2

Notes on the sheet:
Configuration jumpers
Power flags
Boost converter
Descoupling
Video Buffer
SCART
Input signals
10-11V
Video signals
R3 is for current limiting, just in case. It can be replaced with a 0 ohm resistor.

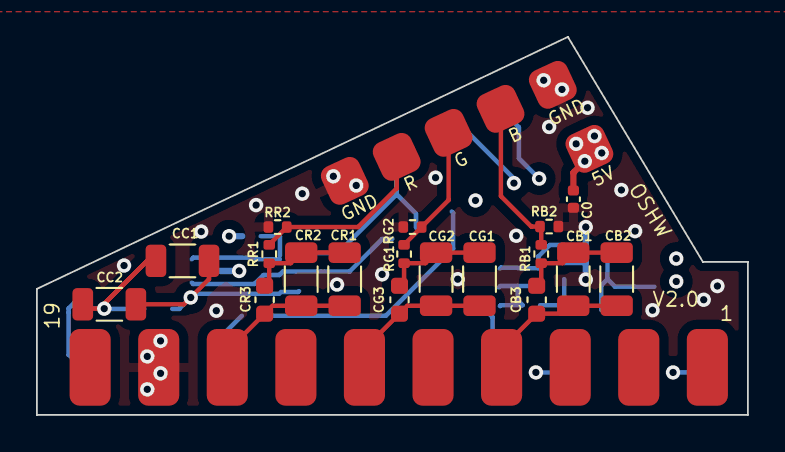
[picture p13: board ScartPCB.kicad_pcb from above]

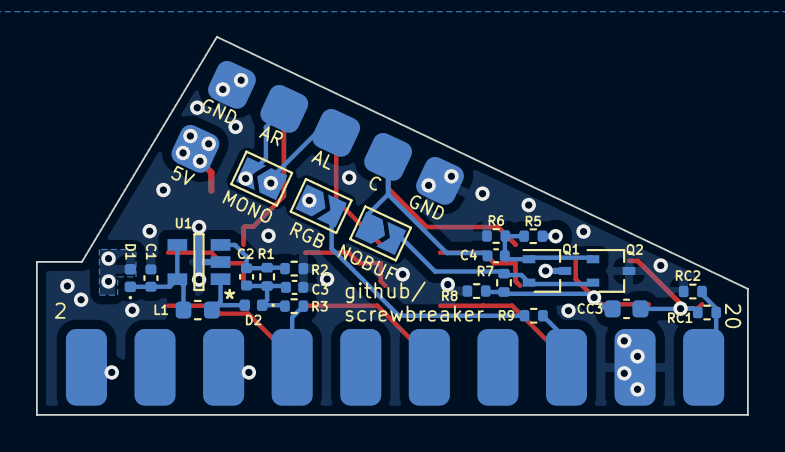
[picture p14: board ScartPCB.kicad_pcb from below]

Board: 4 copper layers, 39.5 x 21.0 mm, 55 parts (30 on the bottom side), 26 nets.

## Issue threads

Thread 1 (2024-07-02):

75 ohm resistors instead of 220uf caps

locutus2000, 2024-07-02:
I am contemplating building my own SCART cables and for PAL SNES I need to place 75 ohm resistors instead of 220uf caps. I could just place these on CR1, CG1 & CB1 and bridge the others right?

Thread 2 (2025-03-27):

Alternative schottky diode

noromamai, 2025-03-27:
First of all, thanks for sharing. Wanted to make my own scart cables for a long time and needed something with the 12v booster.

I am having problems sourcing the schottky diode without having to pay a lot for shipping. If I want to find an alternative, what should I look for? The one in the BOM is 35V 450mV 100mA. Can any of these values be higher or lower?

Thanks!

screwbreaker, 2025-03-27:
Any 0402 diode will probably do the job. A schottky is preferred for this type of applications, but, in this particular case, I doubt is essential. All the characteristics can be lower, just keep an eye on the reverse voltage not less than 12V.

noromamai, 2025-03-27:
Thanks for the quick reply!

Closed 2025-03-27.

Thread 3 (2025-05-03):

Not getting 11-12V from the boost cirtcuitry

noromamai, 2025-05-03:
So I finally got the schottky diodes and finished populating the pcb. It was not automatically switching to 4:3, so I measured the voltage on pin 8 and it is only 7.4V. I double checked all the resistors (R1, R2 and R3), removed them from the pcb as well and the values are all correct. I have also changed R3 to 0 Ohm as well, but the voltage stays at 7.4V. Any suggestions as to what I should check?

screwbreaker, 2025-05-04:
R3 have no effect if you are measuring without connecting the SCART to the TV.
You should get around 11.5V on pin 8.
Try to check the voltage on the feedback pin (pin 3) of the TPS61040DBVR, it should be about 1.3V.

noromamai, 2025-05-04:
The feedback pin is not giving anything. Faulty chip? Maybe I took too long using the heatgun and damaged it.

noromamai, 2025-05-04:
Replaced it with aonther one and it is exactly the same. When the scart is connected I get around 4.6V on the V(in) and around 4.3V on pin8. FB measures 0, but I have around 1.3V on SW. I don't know enough about this, but maybe I was given the wrong IC which has FB and SW the other way around?

screwbreaker, 2025-05-04:
From those readings, seems that the IC is not switching. What you get on pin 8 is the 5V minus the voltage drop on the two diodes.
Is seems strange that you get the wrong IC, where did you got it?
Check the voltage on the enable pin (4) it should be the same of the VCC (pin 5).

noromamai, 2025-05-04:
Looks away in shame... *cough* aliexpress *cough*. We don't have any company selling electronic parts, shipping from digikey, etc. is quite high for just a few components. Top of the IC says PHOI as it should and does not go away after rubbing it with alcohol. Voltage on the EN pin is the same voltage as VCC. Measuring again while connected and turned on, I now only see around 0.6V on SW. Can I test them by just clipping GND and 5V to VCC + EN and then measure what is on SW and FB?

screwbreaker, 2025-05-05:
VCC and EN are connected together, do not try to put EN on GND or you short out VCC. EN must be at VCC.
To measure the SW pin you must use an oscilloscope. No way to check it with a multimeter.
Just to be sure, are you measuring it correctly? I mean, don't use the schematic for the pins reference. In the attached picture I marked the FB pin.
Can you post a picture of the PCB?
Give me the link to the Aliexpress seller. I can try to get some and check if they are good.

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

screwbreaker, 2025-05-06:
That's common in electronic design, pin on the symbol are arranged to make the schematic more readable.
The purpose is to make clear how the circuit work. There is no need to match the same pinout of the real IC. Especially because most of the time the same IC is available in different packages with a different pinout.
In the datasheet you have to watch the pinout page.
The central pin is GND.
So you do have 1.3V on the FB pin. That's odd, because this mean that you must have 11V on the output.
Can you measure again R1 and R2? You can measure them in circuit no need to desolder them. R1 must be around 1.5, 1.6 Mega Ohm, maybe it will take a bit to reach a stable value due to the capacitor. R2 must be around 200K. The measure in circuit can be a bit off but it is ok.

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

noromamai, 2025-05-08:
Measured R1 and R2 in circuit, but values were a bit off with what you indicated, to i desoldered them and measured again and both were correct. After putting everything back again I measured the voltages with the scart connected and not connected. When it is not connected I get 1.3-1.5V on FB. The rest of the voltages are as below.

scart not connected
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

scart connected
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

another batch of the TSP61040 should be arriving in a week or so.

screwbreaker, 2025-05-08:
I've ordered some too from the link you provided.
But that is really odd. Can you try to replace the inductor?

noromamai, 2025-05-08:
Replaced the inductor and am getting the same readings. It was even from a different batch. Only things that have not been replaced yet are the caps.

screwbreaker, 2025-05-10:
The measurement you took are really strange. Try to remove C2, just for test.

noromamai, 2025-05-10:
Removed C2, voltage measured is the same. About 4.7V as well.

screwbreaker, 2025-05-11:
C3 is mandatory, the boost converter can't work without. C2 is only for stability and if broken can mess up with R1.

screwbreaker, 2025-05-14:
I'm glad you solved it! Still strange C0 is for filtering the 5V line, it shouldn't be mandatory. For the video quality be sure to use a good quality cable and don't forget to connect the shield on both sides of the cable. Unfortunately I don't have a PC-Engine so i don't have a reference for this particular console.

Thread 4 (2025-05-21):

Gibberish image on sega mega drive 2

arnes269, 2025-05-21:
when connecting to tv mega drive 2 start doing  gibberish picture seen on pictures. i did everything in schematics .  i only reused cable and scart  connector  all others parts  is brand new . Mega drive 2 is modded with triple bypass and Sega Mega Drive Model 2 Switchless Region, In-Game-Reset & Dual Frequency Oscillator Kit .

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
